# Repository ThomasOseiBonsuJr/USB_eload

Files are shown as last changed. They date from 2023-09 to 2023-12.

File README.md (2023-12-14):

# USB_eload
This is built off of my previous Electronic Load project, a now deleted repository. I wasn't happy with the state and the direction the project was heading so I am creating a new project.

# Features 
- Constant resistance, constant power, constant current, and constant voltage modes. 
- Software fan control instead of hardware fan control. (Hardware fan control was an interesting idea however I think implementing software fan control will allow for a 'clearer' path for project completion)
- 3D printed enclosure with venting for fan
- OLED display for fan speed, load current, voltage, resistance, power, and temperature

- 20V Max Voltage, 5A max current
- software (maybe hardware if it is more reliable) safety features to prevent overcurrent, overvoltage, and over temperature

- The e load will only be controlled with a usb connection 2.0 to a computer 
- Program that sends commands to change eload parameters (either a terminal program or a exe or something that involves an actual UI, currently leaning  towards a program with a UI due the coding experience that could be gained from that)

# Roadmap
- Rough sketch of enclosure UI
- Research electronic load arcitecture (I think the main reason why I consider the first attempt at this project a failure is because of the minimal amount of research and low expectations of the electronic load. While this project will not come near an off the shelf solution it should at least be suitable for an electronics beginner like me)
- Research constant power, constant resistance, and constant voltage modes
- Learn fusion 360 
- Research the usb 2.0 protocol
- Decide MCU (mcu on old electronic load might be good enough)
- Block diagrams of subsystems in the electronic load
- 1st draft of schematic and layout 
- Review, iterate if needed
- Design enclosure
- Order parts, solder, and test (currently away from home so this last step might be delayed for a bit)

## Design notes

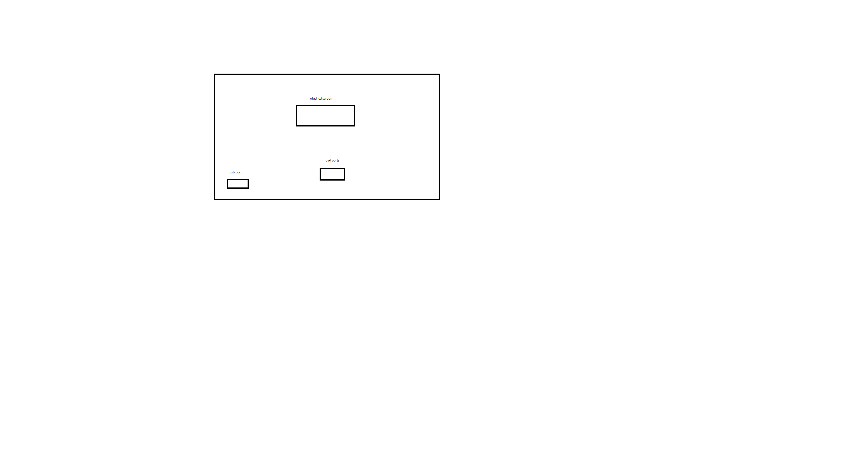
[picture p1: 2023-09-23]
plannedui.png

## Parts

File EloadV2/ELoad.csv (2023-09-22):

Source: | D:\ELoad\ELoad.kicad_sch
Date: | 2023-02-19 2:59:53 AM
Tool: | Eeschema (6.0.5)
Generator: | D:\KiCad\6.0\bin\scripting\plugins/bom_csv_grouped_by_value_with_fp.py
Component Count: | 126
Ref | Qnty | Value | Cmp name | Footprint | Description | Vendor
C1, | 1 | 10u | C_Small | Capacitor_SMD:C_1206_3216Metric_Pad1.33x1.80mm_HandSolder | Unpolarized capacitor, small symbol
C2, | 1 | 10uF | C_Small | Capacitor_SMD:C_0603_1608Metric_Pad1.08x0.95mm_HandSolder | Unpolarized capacitor, small symbol
C3, C7, C18, | 3 | 0.1u | C_Small | Capacitor_SMD:C_0603_1608Metric_Pad1.08x0.95mm_HandSolder | Unpolarized capacitor, small symbol
C4, C8, C9, C26, | 4 | 22u | C_Small | Capacitor_SMD:C_0603_1608Metric_Pad1.08x0.95mm_HandSolder | Unpolarized capacitor, small symbol
C5, C15, C19, C21, C22, C23, | 6 | 100n | C_Small | Capacitor_SMD:C_0603_1608Metric_Pad1.08x0.95mm_HandSolder | Unpolarized capacitor, small symbol
C6, C10, C16, | 3 | 1u | C_Small | Capacitor_SMD:C_0603_1608Metric_Pad1.08x0.95mm_HandSolder | Unpolarized capacitor, small symbol
C11, C12, | 2 | 10u | C_Polarized_Small | Capacitor_Tantalum_SMD:CP_EIA-7343-30_AVX-N_Pad2.25x2.55mm_HandSolder | Polarized capacitor, small symbol
C13, | 1 | 0.01u | C_Small | Capacitor_SMD:C_0603_1608Metric_Pad1.08x0.95mm_HandSolder | Unpolarized capacitor, small symbol
C14, | 1 | 4.7u | C_Small | Capacitor_SMD:C_0603_1608Metric_Pad1.08x0.95mm_HandSolder | Unpolarized capacitor, small symbol
C17, C20, C24, | 3 | 10n | C_Small | Capacitor_SMD:C_0603_1608Metric_Pad1.08x0.95mm_HandSolder | Unpolarized capacitor, small symbol
C25, | 1 | 10u | C_Small | Capacitor_SMD:C_0603_1608Metric_Pad1.08x0.95mm_HandSolder | Unpolarized capacitor, small symbol
D1, | 1 | D_Schottky | D_Schottky | Diode_SMD:D_SMA_Handsoldering | Schottky diode
D2, | 1 | LED | LED | Diode_SMD:D_1210_3225Metric_Pad1.42x2.65mm_HandSolder | Light emitting diode
F1, | 1 | Fuse | Fuse | Fuse:Fuse_0805_2012Metric_Pad1.15x1.40mm_HandSolder | Fuse
H1, H2, H3, H4, | 4 | MountingHole | MountingHole | MountingHole:MountingHole_4.3mm_M4_DIN965_Pad_TopBottom | Mounting Hole without connection
J1, | 1 | Power Input | Barrel_Jack | Connector_BarrelJack:BarrelJack_CUI_PJ-063AH_Horizontal | DC Barrel Jack
J2, | 1 | Conn_01x02 | Conn_01x02 | TerminalBlock_Phoenix:TerminalBlock_Phoenix_PT-1,5-2-3.5-H_1x02_P3.50mm_Horizontal | Generic connector, single row, 01x02, script generated (kicad-library-utils/schlib/autogen/connector/)
J3, | 1 | OLED | Conn_01x06 | Connector_PinSocket_2.54mm:PinSocket_1x06_P2.54mm_Vertical | Generic connector, single row, 01x06, script generated (kicad-library-utils/schlib/autogen/connector/)
J4, | 1 | ENCODER | Conn_01x06 | Connector_PinSocket_2.54mm:PinSocket_1x06_P2.54mm_Vertical | Generic connector, single row, 01x06, script generated (kicad-library-utils/schlib/autogen/connector/)
J5, | 1 | SWDEBUG | Conn_01x06 | Connector_PinSocket_2.54mm:PinSocket_1x06_P2.54mm_Vertical | Generic connector, single row, 01x06, script generated (kicad-library-utils/schlib/autogen/connector/)
L1, | 1 | 2.2u | L_Small | Inductor_SMD:L_1008_2520Metric_Pad1.43x2.20mm_HandSolder | Inductor, small symbol
L2, | 1 | 39n | L_Small | Inductor_SMD:L_1008_2520Metric_Pad1.43x2.20mm_HandSolder | Inductor, small symbol
M1, | 1 | Fan_4pin | Fan_4pin | Connector:FanPinHeader_1x04_P2.54mm_Vertical_NoRandomHole | Fan, tacho output, PWM input, 4-pin connector
Q1, | 1 | Q_PMOS_GSD | Q_PMOS_GSD | Package_TO_SOT_SMD:SOT-23_Handsoldering | P-MOSFET transistor, gate/source/drain
Q2, Q3, | 2 | Q_NPN_BCE | Q_NPN_BCE | Package_TO_SOT_SMD:SOT-23_Handsoldering | NPN transistor, base/collector/emitter
Q4, | 1 | Q_NMOS_GDS | Q_NMOS_GDS | Package_TO_SOT_THT:TO-220-3_Horizontal_TabUp | N-MOSFET transistor, gate/drain/source
R1, R15, | 2 | 70k | R_Small | Resistor_SMD:R_0805_2012Metric_Pad1.20x1.40mm_HandSolder | Resistor, small symbol
R2, R3, R5, R6, R8, R9, R10, R11, R12, R19, R21, R23, R28, R29, R33, R34, R35, R37, R38, | 19 | 10k | R_Small | Resistor_SMD:R_0805_2012Metric_Pad1.20x1.40mm_HandSolder | Resistor, small symbol
R4, R22, | 2 | 1.7k | R_Small | Resistor_SMD:R_0805_2012Metric_Pad1.20x1.40mm_HandSolder | Resistor, small symbol
R7, R17, R31, | 3 | 100k | R_Small | Resistor_SMD:R_0805_2012Metric_Pad1.20x1.40mm_HandSolder | Resistor, small symbol
R13, | 1 | 8k | R_Small | Resistor_SMD:R_0805_2012Metric_Pad1.20x1.40mm_HandSolder | Resistor, small symbol
R14, R24, | 2 | 3.3k | R_Small | Resistor_SMD:R_0805_2012Metric_Pad1.20x1.40mm_HandSolder | Resistor, small symbol
R16, | 1 | 20k | R_Small | Resistor_SMD:R_0805_2012Metric_Pad1.20x1.40mm_HandSolder | Resistor, small symbol
R18, | 1 | 52.3k | R_Small | Resistor_SMD:R_0805_2012Metric_Pad1.20x1.40mm_HandSolder | Resistor, small symbol
R20, | 1 | 1M | R_Small | Resistor_SMD:R_0805_2012Metric_Pad1.20x1.40mm_HandSolder | Resistor, small symbol
R25, R39, R40, R41, R42, R55, | 6 | 1k | R_Small | Resistor_SMD:R_0805_2012Metric_Pad1.20x1.40mm_HandSolder | Resistor, small symbol
R27, R36, | 2 | 5k | R_Small | Resistor_SMD:R_0805_2012Metric_Pad1.20x1.40mm_HandSolder | Resistor, small symbol
R30, | 1 | 2.5k | R_Small | Resistor_SMD:R_0805_2012Metric_Pad1.20x1.40mm_HandSolder | Resistor, small symbol
R32, | 1 | 2k | R_Small | Resistor_SMD:R_0805_2012Metric_Pad1.20x1.40mm_HandSolder | Resistor, small symbol
R43, R44, | 2 | 4.7k | R_Small | Resistor_SMD:R_0805_2012Metric_Pad1.20x1.40mm_HandSolder | Resistor, small symbol
R45, R46, R47, R48, R49, R50, R51, R52, R53, R54, | 10 | 10 | R_Small | Resistor_THT:R_Axial_DIN0207_L6.3mm_D2.5mm_P10.16mm_Horizontal | Resistor, small symbol
SW1, | 1 | SW_Push | SW_Push | Button_Switch_SMD:SW_SPST_B3U-1000P | Push button switch, generic, two pins
TP1, TP3, TP4, TP6, TP7, TP8, TP9, TP10, | 8 | TestPoint_Probe | TestPoint_Probe | TestPoint:TestPoint_Pad_1.5x1.5mm | test point (alternative probe-style design)
TP2, TP5, | 2 | Test | TestPoint_Probe | TestPoint:TestPoint_Pad_1.5x1.5mm | test point (alternative probe-style design)
U1, U5, U8, U10, U14, | 5 | TL072 | TL072 | Package_SO:SOIC-8_3.9x4.9mm_P1.27mm | Dual Low-Noise JFET-Input Operational Amplifiers, DIP-8/SOIC-8
U2, | 1 | AZ1117-3.3 | AZ1117-3.3 | Package_TO_SOT_SMD:SOT-89-3_Handsoldering | 1A 20V Fixed LDO Linear Regulator, 3.3V, SOT-89/SOT-223/TO-220/TO-252/TO-263
U3, | 1 | MCP9700AT-ELT | MCP9700AT-ELT | Package_TO_SOT_SMD:SOT-353_SC-70-5 | Low power, analog thermistor temperature sensor, Â±2C accuracy, -40C to +125C, in SC-70-5
U4, | 1 | AP62250WU-7 | AP62250WU-7 | Package_TO_SOT_SMD:TSOT-23-6
U6, | 1 | TL074 | TL074 | Package_SO:SOIC-14_3.9x8.7mm_P1.27mm | Quad Low-Noise JFET-Input Operational Amplifiers, DIP-14/SOIC-14
U7, | 1 | P7805-12/N | P7805-12{slash}N | P7805-Q24-S12-S:P78E12-1000
U9, | 1 | LM393 | LM393 | Package_SO:SOIC-8_3.9x4.9mm_P1.27mm | Low-Power, Low-Offset Voltage, Dual Comparators, DIP-8/SOIC-8/TO-99-8
U11, | 1 | LTV-817S | LTV-817S | Package_DIP:SMDIP-4_W9.53mm | DC Optocoupler, Vce 35V, CTR 50%, SMDIP-4
U12, | 1 | STM32L433CCTx | STM32L433CCTx | Package_QFP:LQFP-48_7x7mm_P0.5mm | ARM Cortex-M4 MCU, 256KB flash, 64KB RAM, 80MHz, 1.71-3.6V, 38 GPIO, LQFP-48
U13, | 1 | AZ1117-5.0 | AZ1117-5.0 | Package_TO_SOT_SMD:SOT-223-3_TabPin2 | 1A 20V Fixed LDO Linear Regulator, 5.0V, SOT-89/SOT-223/TO-220/TO-252/TO-263
U15, | 1 | MCP9700AT-ETT | MCP9700AT-ETT | Package_TO_SOT_THT:TO-92 | Low power, analog thermistor temperature sensor, Â±2C accuracy, -40C to +125C, in SOT-23-3
X1, | 1 | ECS-2520MV-160-CN-TR | ECS-2520MV-xxx-xx | Oscillator:Oscillator_SMD_ECS_2520MV-xxx-xx-4Pin_2.5x2.0mm | HCMOS Crystal Clock Oscillator, 2.5x2.0 mm SMD

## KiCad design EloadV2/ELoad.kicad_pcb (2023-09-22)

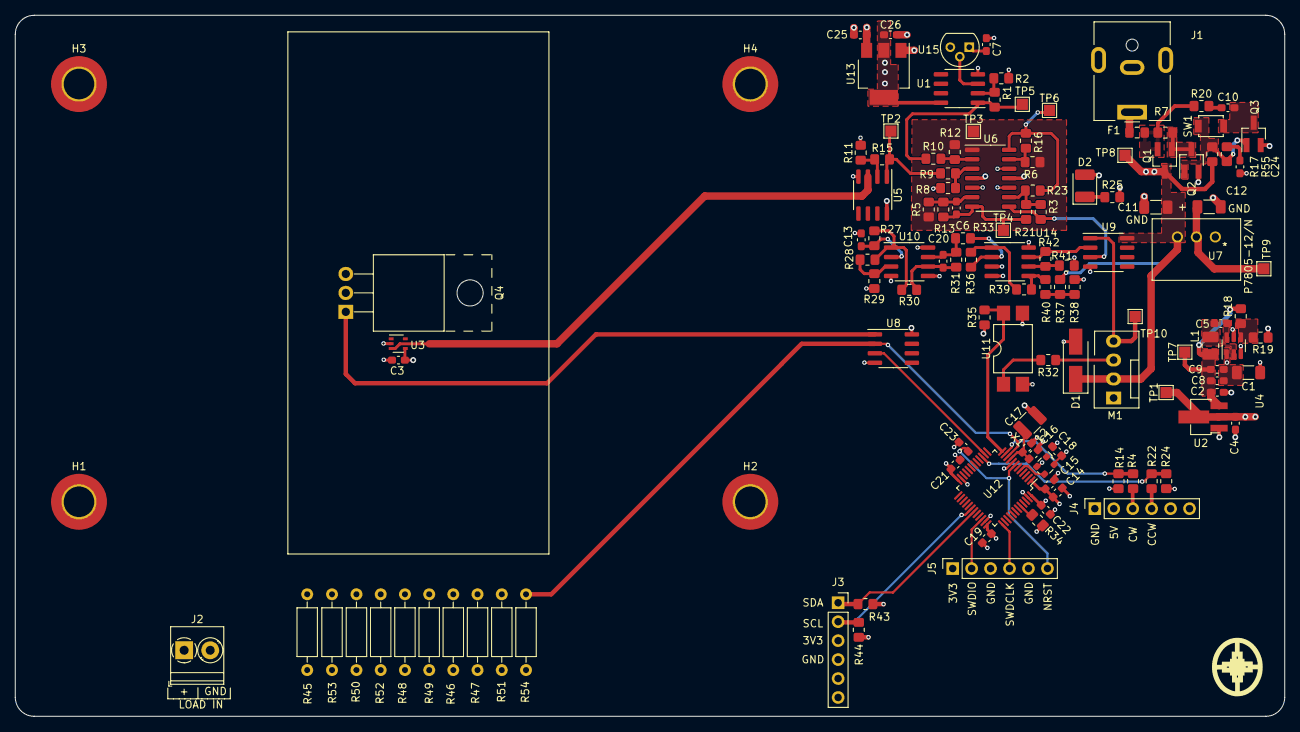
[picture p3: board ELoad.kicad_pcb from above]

Board: 4 copper layers, 170.2 x 94.0 mm, 126 parts (0 on the bottom side), 63 nets.

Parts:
C1, C11, C12: 10u; C_1206_3216Metric_Pad1.33x1.80mm_HandSolder
C2, C25: 10u; C_0603_1608Metric_Pad1.08x0.95mm_HandSolder
C3, C7, C18: 0.1u; C_0603_1608Metric_Pad1.08x0.95mm_HandSolder
C4, C8, C9, C26: 22u; C_0603_1608Metric_Pad1.08x0.95mm_HandSolder
C5, C15, C19, C21, C22, C23: 100n; C_0603_1608Metric_Pad1.08x0.95mm_HandSolder
C6, C10, C16: 1u; C_0603_1608Metric_Pad1.08x0.95mm_HandSolder
C13: 0.01u; C_0603_1608Metric_Pad1.08x0.95mm_HandSolder
C14: 4.7u; C_0603_1608Metric_Pad1.08x0.95mm_HandSolder
C17, C20, C24: 10n; C_0603_1608Metric_Pad1.08x0.95mm_HandSolder
D1: D_Schottky; D_SMA_Handsoldering
D2: LED; D_1210_3225Metric_Pad1.42x2.65mm_HandSolder
F1: Fuse; Fuse_0805_2012Metric_Pad1.15x1.40mm_HandSolder
H1, H2, H3, H4: MountingHole; MountingHole_4.3mm_M4_DIN965_Pad_TopBottom
J1: Power Input; BarrelJack_CUI_PJ-063AH_Horizontal
J2: Conn_01x02; TerminalBlock_Phoenix_PT-1,5-2-3.5-H_1x02_P3.50mm_Horizontal
J3: OLED; PinSocket_1x06_P2.54mm_Vertical
J4: ENCODER; PinSocket_1x06_P2.54mm_Vertical
J5: SWDEBUG; PinSocket_1x06_P2.54mm_Vertical
L1: 2.2u; L_1008_2520Metric_Pad1.43x2.20mm_HandSolder
L2: 39n; L_1210_3225Metric
M1: Fan_4pin; FanPinHeader_1x04_P2.54mm_Vertical_NoRandomHole
Q1: Q_PMOS_GSD; SOT-23_Handsoldering
Q2, Q3: Q_NPN_BEC; SOT-23_Handsoldering
Q4: Q_NMOS_GDS; TO-220-3_Horizontal_TabUp
R1, R15: 70k; R_0805_2012Metric_Pad1.20x1.40mm_HandSolder
R2, R3, R5, R6, R8, R9, R10, R11, R12, R19, R21, R23, R28, R29, R33, R34, R35, R37, R38: 10k; R_0805_2012Metric_Pad1.20x1.40mm_HandSolder
R4, R22: 1.7k; R_0805_2012Metric_Pad1.20x1.40mm_HandSolder
R7, R17, R31: 100k; R_0805_2012Metric_Pad1.20x1.40mm_HandSolder
R13: 8k; R_0805_2012Metric_Pad1.20x1.40mm_HandSolder
R14, R24: 3.3k; R_0805_2012Metric_Pad1.20x1.40mm_HandSolder
R16: 20k; R_0805_2012Metric_Pad1.20x1.40mm_HandSolder
R18: 52.3k; R_0805_2012Metric_Pad1.20x1.40mm_HandSolder
R20: 1M; R_0805_2012Metric_Pad1.20x1.40mm_HandSolder
R25, R39, R40, R41, R42, R55: 1k; R_0805_2012Metric_Pad1.20x1.40mm_HandSolder
R27, R36: 5k; R_0805_2012Metric_Pad1.20x1.40mm_HandSolder
R30: 2.5k; R_0805_2012Metric_Pad1.20x1.40mm_HandSolder
R32: 2k; R_0805_2012Metric_Pad1.20x1.40mm_HandSolder
R43, R44: 4.7k; R_0805_2012Metric_Pad1.20x1.40mm_HandSolder
R45, R46, R47, R48, R49, R50, R51, R52, R53, R54: 10; R_Axial_DIN0207_L6.3mm_D2.5mm_P10.16mm_Horizontal
SW1: SW_Push; SW_SPST_B3U-1000P
TP1, TP3, TP4, TP6, TP7, TP8, TP9, TP10: TestPoint_Probe; TestPoint_Pad_1.5x1.5mm
TP2, TP5: Test; TestPoint_Pad_1.5x1.5mm
U1, U5, U8, U10, U14: TL072; SOIC-8_3.9x4.9mm_P1.27mm
U2: AZ1117-3.3; SOT-89-3_Handsoldering
U3: MCP9700AT-ELT; SOT-353_SC-70-5
U4: AP62250WU-7; TSOT-23-6
U6: TL074; SOIC-14_3.9x8.7mm_P1.27mm
U7: P7805-12/N; P78E12-1000
U9: LM393; SOIC-8_3.9x4.9mm_P1.27mm
U11: LTV-817S; SMDIP-4_W9.53mm
U12: STM32L433CCTx; LQFP-48_7x7mm_P0.5mm
U13: AZ1117-5.0; SOT-223-3_TabPin2
U15: MCP9700AT-ETT; TO-92
X1: ECS-2520MV-160-CN-TR; Oscillator_SMD_ECS_2520MV-xxx-xx-4Pin_2.5x2.0mm

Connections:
+3.3VA: C16.1, C17.1, L2.2, U12.9 (VDDA)
+3V3: C4.1, C14.1, C15.1, C18.1, C19.1, C21.1, C22.1, J3.3, J5.1, L2.1, R35.1, R43.1, R44.1, TP1.1, U2.2 (VO), U12.1 (VBAT), U12.24 (VDD), U12.36 (VDDUSB), U12.48 (VDD), X1.4 (VDD)
+5V: C3.2, C7.2, C26.1, J4.2, U1.8 (V+), U3.4 (Vdd), U5.8 (V+), U8.8 (V+), U13.2 (VO), U15.1 (Vdd)
+12V: C1.1, C11.1, C25.1, D1.1 (K), D2.2 (A), M1.2 (+), Q1.3 (D), R17.1, R37.2, TP8.1, U4.3 (VIN), U4.5 (EN), U6.4 (V+), U7.1 (Vin), U9.8 (V+), U10.4 (V-), U13.3 (VI), U14.4 (V-)
-12V: C12.2, TP9.1, U6.11 (V-), U7.2 (Vout), U10.8 (V+), U14.8 (V+)
/BST: C5.1, U4.6 (BST)
/CCW: J4.4, R22.2
/CURRENT: Q4.3 (S), R45.1, R46.1, R47.1, R48.1, R49.1, R50.1, R51.1, R52.1, R53.1, R54.1, U8.2 (-), U12.10 (PA0)
/CW: J4.3, R4.2
/DAC: U8.3 (+), U12.14 (PA4)
/FANPWM: M1.4 (PWM), TP10.1, U9.1
/FB: R18.2, R19.1, U4.4 (FB)
/NRST: C23.2, J5.6, U12.7 (NRST)
/OSC_IN: U12.5 (PH0), X1.3 (OUT)
/ROT_CCW: R22.1, R24.2, U12.15 (PA5)
/ROT_CW: R4.1, R14.2, U12.11 (PA1)
/SCL: J3.2, R44.2, U12.30 (PA9)
/SDA: J3.1, R43.2, U12.31 (PA10)
/SW: C5.2, L1.1, U4.2 (SW)
/SWDCLK: J5.4, U12.37 (PA14)
/SWDIO: J5.2, U12.34 (PA13)
/TACH: R35.2, U11.4, U12.12 (PA2)
/TEMP: R9.1, R15.1, TP2.1, U5.1
/aTempout: U1.3 (+), U15.2 (Vout)
/addtri+: R39.2, R40.2, U14.5 (+)
/addtri-: R41.2, R42.1, U14.6 (-)
/ambient: R1.1, R10.1, TP5.1, U1.1
/atempdivider: R1.2, R2.1, U1.2 (-)
/buttonBase: Q2.1 (B), Q3.1 (B), R17.2, R55.1, SW1.1
/buttonCollector: C10.2, Q3.3 (C), SW1.2
/buttonGate: Q1.1 (G), Q2.3 (C), R7.2
/cathode: D2.1 (K), R25.1
/error: R5.1, R6.1, R12.2, TP3.1, U6.1
/error+: R8.2, R9.2, U6.3 (+)
/error-: R10.2, R12.1, U6.2 (-)
/integrator: C6.1, R13.2, R21.1, TP4.1, U6.7
/integrator-: C6.2, R5.2, R13.1, U6.6 (-)
/linout: Q4.1 (G), U8.1
/loadIN: J2.1, Q4.2 (D)
/pidOUT: R3.2, U6.8, U9.3 (+)
/prop: R16.2, R23.1, TP6.1, U6.14
/prop-: R6.2, R16.1, U6.13 (-)
/square+: R28.1, R29.2, U10.3 (+)
/square-: C13.2, R27.1, U10.2 (-)
/squareout: R27.2, R28.2, R30.2, U10.1
/summ-: R3.1, R21.2, R23.2, U6.9 (-)
/tempdivider: R11.1, R15.2, U5.2 (-)
/tempout: U3.3 (Vout), U5.3 (+)
/tri-: C20.2, R30.1, R31.2, U10.6 (-)
/tribias: R37.1, R38.2, R40.1
/trihalf-: R33.2, R36.1, U14.2 (-)
/trihalfout: R36.2, R39.1, U14.1
/triout: C20.1, R31.1, R33.1, U10.7
/triwave: R42.2, U9.2 (-), U14.7
GND: C1.2, C2.2, C3.1, C4.2, C7.1, C8.2, C9.2, C11.2, C12.1, C13.1, C14.2, C15.2, C16.2, C17.2, C18.2, C19.2, C21.2, C22.2, C23.1, C24.2, C25.2, C26.2, D1.2 (A), J1.2, J2.2, J3.4, J4.1, J5.3, J5.5, M1.1 (-), Q2.2 (E), Q3.2 (E), R2.2, R8.1, R11.2, R14.1, R19.2, R24.1, R25.2, R29.1, R34.2, R38.1, R41.1, R45.2, R46.2, R47.2, R48.2, R49.2, R50.2, R51.2, R52.2, R53.2, R54.2, U1.4 (V-), U2.1 (GND), U3.2 (GND), U4.1 (GND), U5.4 (V-), U6.5 (+), U6.10 (+), U6.12 (+), U7.3 (GND), U8.4 (V-), U9.4 (V-), U10.5 (+), U11.2, U11.3, U12.8 (VSSA), U12.23 (VSS), U12.35 (VSS), U12.47 (VSS), U13.1 (GND), U14.3 (+), U15.3 (GND), X1.2 (GND)
unnamed: C10.1, R20.2
unnamed: C24.1, R55.2
unnamed: F1.1, J1.1
unnamed: F1.2, Q1.2 (S), R7.1, R20.1
unnamed: M1.3 (Tacho), R32.1
unnamed: R32.2, U11.1
unnamed: R34.1, U12.44 (PH3)
VDC: C2.1, C8.1, C9.1, L1.2, R18.1, TP7.1, U2.3 (VI)
